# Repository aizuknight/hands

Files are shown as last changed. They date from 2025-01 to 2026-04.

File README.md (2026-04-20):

# hands
**hands** is a keyboard which has 36 keys in total. I had been struggling with touch typing on QWERTY + row staggered keyboards. They are literally inefficient to type with, especially special keys like `ESC`, `Shift`, `Ctrl`, `Back Space`, `Enter/Return` and arrow keys. I had to forcely extend my fingers or move my hands. That's very annoying and tiring. **hands** solves this problem with split thumb keys and "Tap and Hold".

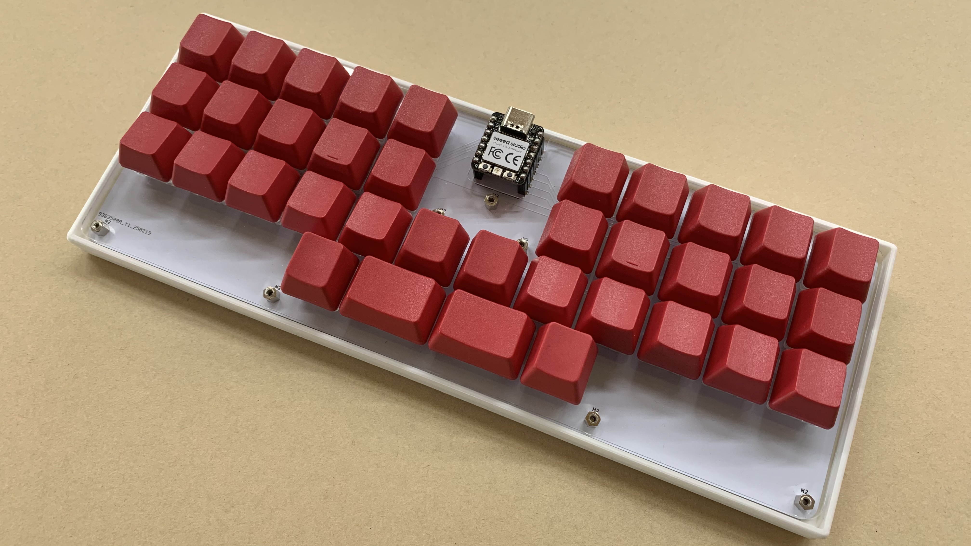
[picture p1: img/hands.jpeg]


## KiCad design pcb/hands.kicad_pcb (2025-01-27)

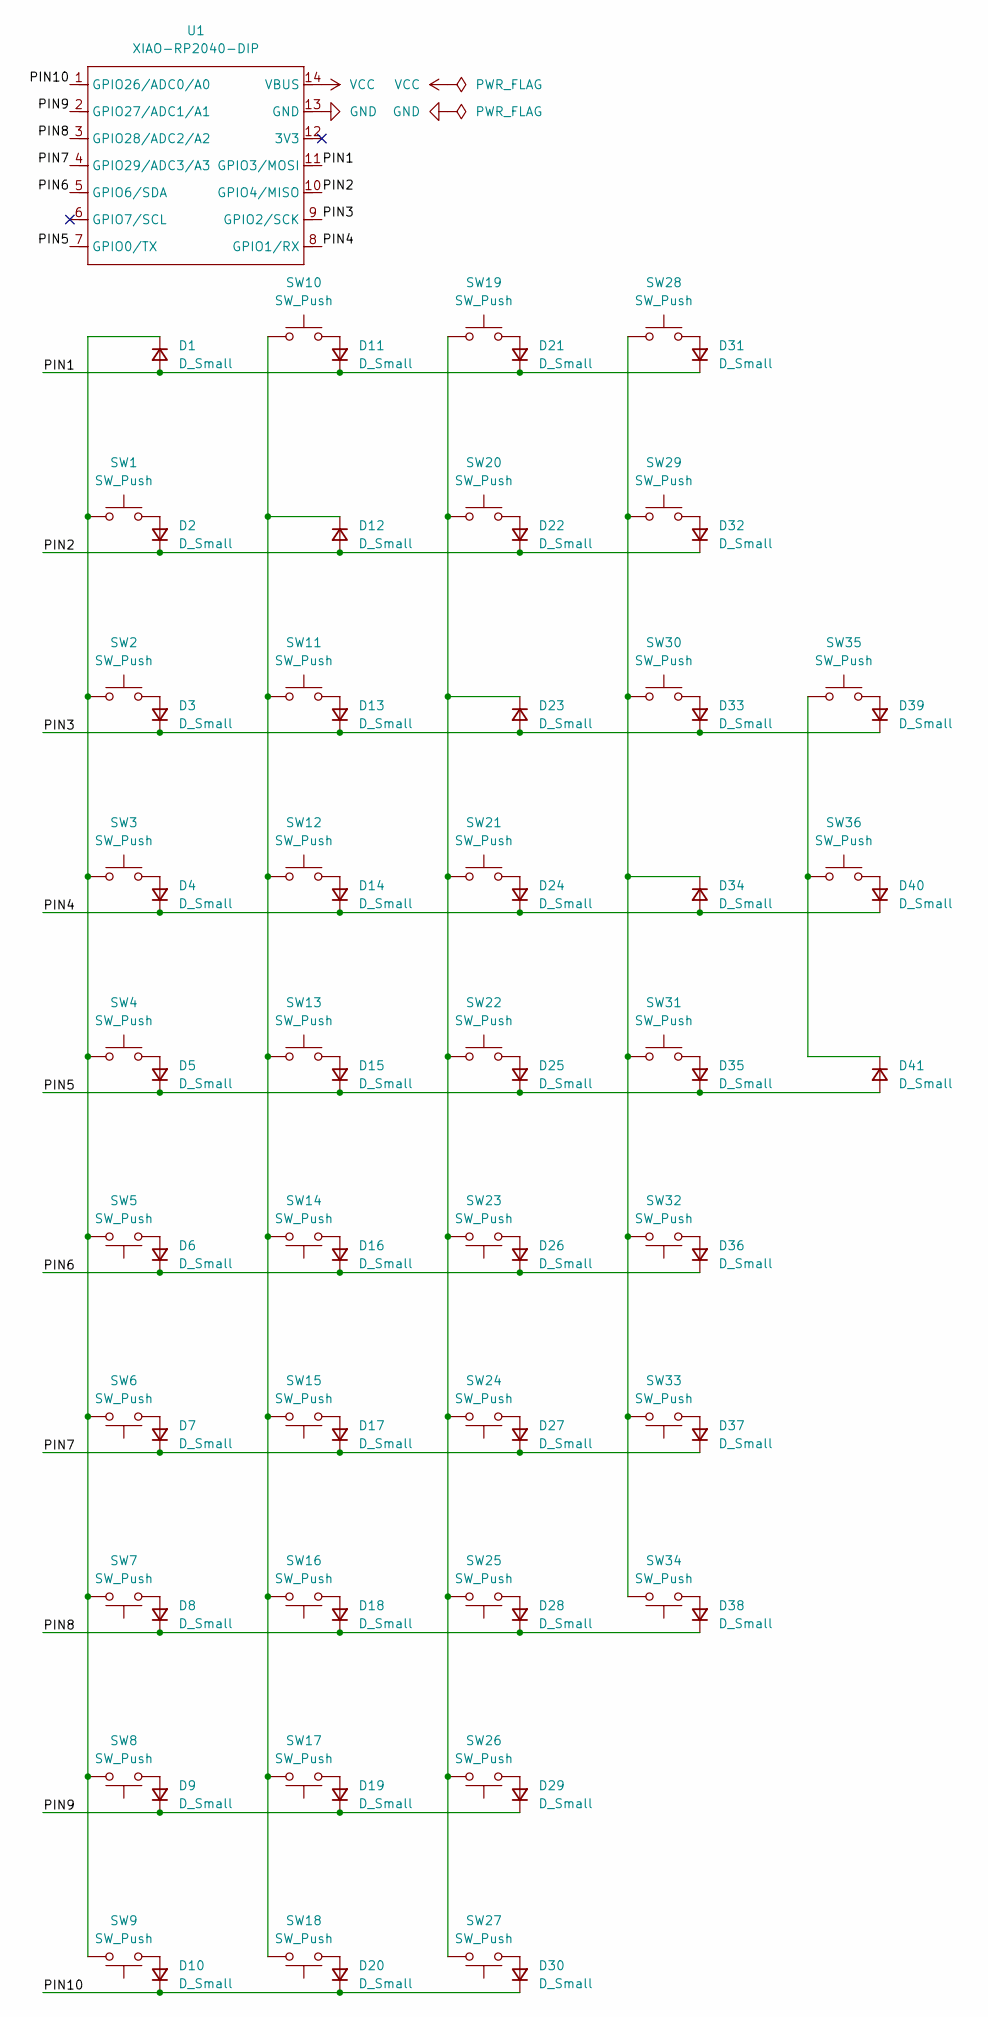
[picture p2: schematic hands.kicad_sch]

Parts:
D1, D2, D3, D4, D5, D6, D7, D8, D9, D10, D11, D12, D13, D14, D15, D16, D17, D18, D19, D20, D21, D22, D23, D24, D25, D26, D27, D28, D29, D30, D31, D32, D33, D34, D35, D36, D37, D38, D39, D40, D41: D_Small; D3_SMD_v2
SW1, SW2, SW3, SW4, SW5, SW6, SW7, SW8, SW9, SW10, SW11, SW12, SW13, SW14, SW15, SW16, SW17, SW18, SW19, SW20, SW21, SW22, SW23, SW24, SW25, SW26, SW27, SW28, SW29, SW30, SW31, SW32, SW34, SW35: SW_Push; CherryMX_Hotswap
SW33, SW36: SW_Push; CherryMX_Hotswap_1.5u
U1: XIAO-RP2040-DIP

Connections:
/PIN1: D1.2 (A), D11.1 (K), D21.1 (K), D31.1 (K), U1.11 (GPIO3/MOSI)
/PIN2: D2.1 (K), D12.2 (A), D22.1 (K), D32.1 (K), U1.10 (GPIO4/MISO)
/PIN3: D3.1 (K), D13.1 (K), D23.2 (A), D33.1 (K), D39.1 (K), U1.9 (GPIO2/SCK)
/PIN4: D4.1 (K), D14.1 (K), D24.1 (K), D34.2 (A), D40.1 (K), U1.8 (GPIO1/RX)
/PIN5: D5.1 (K), D15.1 (K), D25.1 (K), D35.1 (K), D41.2 (A), U1.7 (GPIO0/TX)
/PIN6: D6.1 (K), D16.1 (K), D26.1 (K), D36.1 (K), U1.5 (GPIO6/SDA)
/PIN7: D7.1 (K), D17.1 (K), D27.1 (K), D37.1 (K), U1.4 (GPIO29/ADC3/A3)
/PIN8: D8.1 (K), D18.1 (K), D28.1 (K), D38.1 (K), U1.3 (GPIO28/ADC2/A2)
/PIN9: D9.1 (K), D19.1 (K), D29.1 (K), U1.2 (GPIO27/ADC1/A1)
/PIN10: D10.1 (K), D20.1 (K), D30.1 (K), U1.1 (GPIO26/ADC0/A0)
GND: U1.13 (GND)
unnamed: D1.1 (K), SW1.1, SW2.1, SW3.1, SW4.1, SW5.2, SW6.2, SW7.2, SW8.2, SW9.2
unnamed: D2.2 (A), SW1.2
unnamed: D3.2 (A), SW2.2
unnamed: D4.2 (A), SW3.2
unnamed: D5.2 (A), SW4.2
unnamed: D6.2 (A), SW5.1
unnamed: D7.2 (A), SW6.1
unnamed: D8.2 (A), SW7.1
unnamed: D9.2 (A), SW8.1
unnamed: D10.2 (A), SW9.1
unnamed: D11.2 (A), SW10.2
unnamed: D12.1 (K), SW10.1, SW11.1, SW12.1, SW13.1, SW14.2, SW15.2, SW16.2, SW17.2, SW18.2
unnamed: D13.2 (A), SW11.2
unnamed: D14.2 (A), SW12.2
unnamed: D15.2 (A), SW13.2
unnamed: D16.2 (A), SW14.1
unnamed: D17.2 (A), SW15.1
unnamed: D18.2 (A), SW16.1
unnamed: D19.2 (A), SW17.1
unnamed: D20.2 (A), SW18.1
unnamed: D21.2 (A), SW19.2
unnamed: D22.2 (A), SW20.2
unnamed: D23.1 (K), SW19.1, SW20.1, SW21.1, SW22.1, SW23.2, SW24.2, SW25.2, SW26.2, SW27.2
unnamed: D24.2 (A), SW21.2
unnamed: D25.2 (A), SW22.2
unnamed: D26.2 (A), SW23.1
unnamed: D27.2 (A), SW24.1
unnamed: D28.2 (A), SW25.1
unnamed: D29.2 (A), SW26.1
unnamed: D30.2 (A), SW27.1
unnamed: D31.2 (A), SW28.2
unnamed: D32.2 (A), SW29.2
unnamed: D33.2 (A), SW30.2
unnamed: D34.1 (K), SW28.1, SW29.1, SW30.1, SW31.1, SW32.2, SW33.2, SW34.2
unnamed: D35.2 (A), SW31.2
unnamed: D36.2 (A), SW32.1
unnamed: D37.2 (A), SW33.1
unnamed: D38.2 (A), SW34.1
unnamed: D39.2 (A), SW35.2
unnamed: D40.2 (A), SW36.2
unnamed: D41.1 (K), SW35.1, SW36.1
VCC: U1.14 (VBUS)

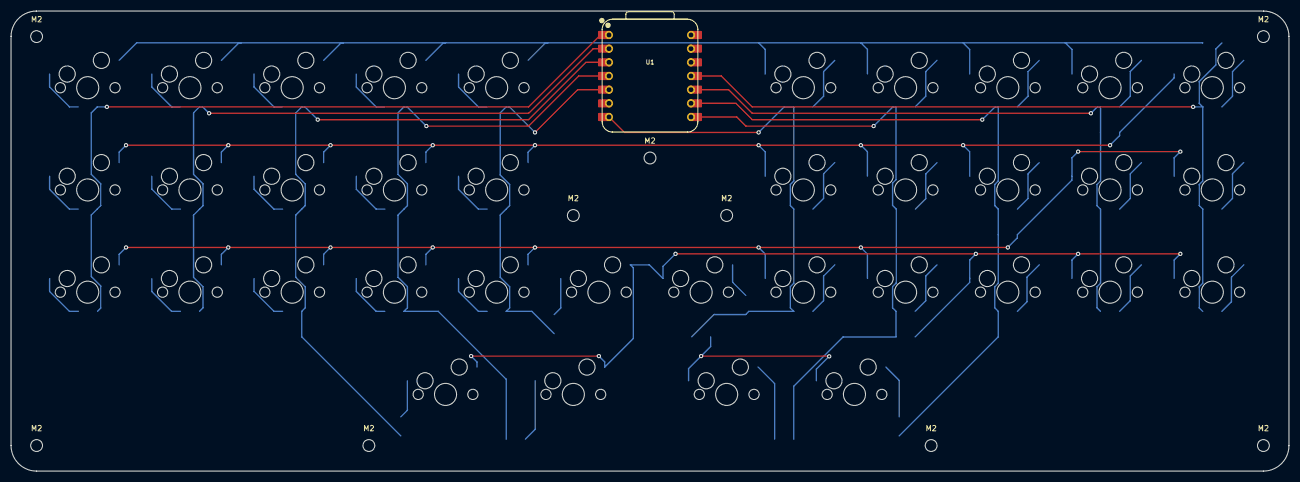
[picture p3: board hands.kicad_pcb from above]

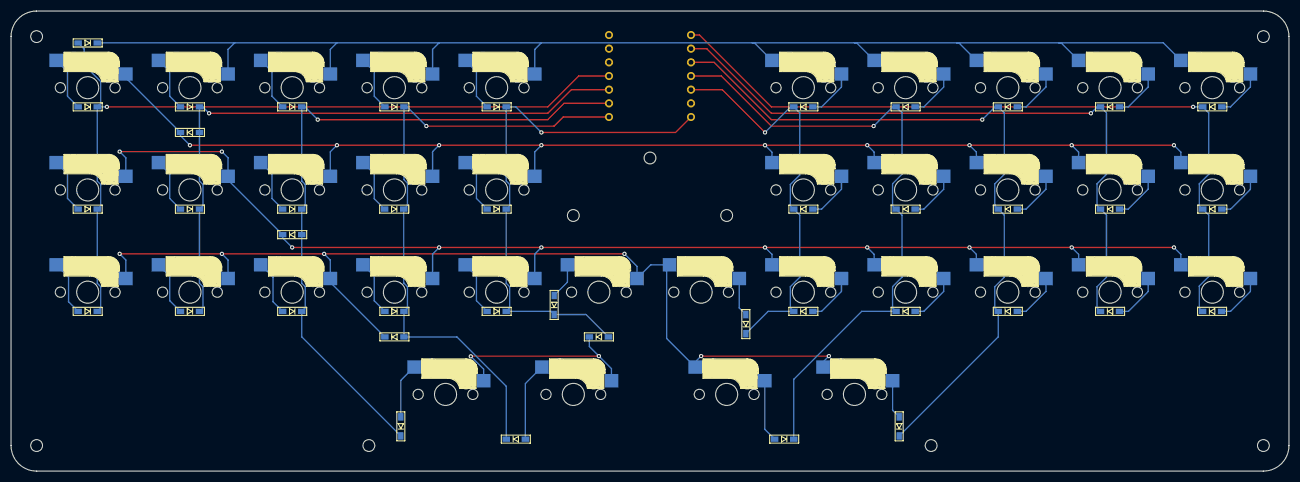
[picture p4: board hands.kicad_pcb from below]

Board: 2 copper layers, 237.5 x 85.5 mm, 87 parts (41 on the bottom side), 51 nets.

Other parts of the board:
M2, M2#2, M2#3, M2#4, M2#5, M2#6, M2#7, M2#8, M2#9: MountingHole_2.2mm_M2

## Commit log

2025-01-27 Fixed key pitch and added mounting hole
    [hands.kicad_pcb]
2026-04-20 Move pcb design files to pcb directory
    [hands.kicad_pcb, hands.kicad_sch]
